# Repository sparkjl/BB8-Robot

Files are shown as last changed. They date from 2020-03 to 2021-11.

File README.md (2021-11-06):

## STAR WARS星战之旅: BB8球形机器人制作 
> 基于TI MSP-EXP430G2 LaunchPad硬件平台，软件、硬件、结构完全开源。
- 一切源于40多年的星战情怀:  
[星球大战7：原力觉醒](https://www.bilibili.com/video/av74977133?from=search&seid=1754264535096664915)
- YouTube上的BB8 Robot拆机视频:  
[今天就拆你了 Cracking Open - Sphero BB-8 Star Wars toy](https://www.bilibili.com/video/av2889876?from=search&seid=3099549580609771673)

### 1. 结构
SolidWorks渲染的结构外观:
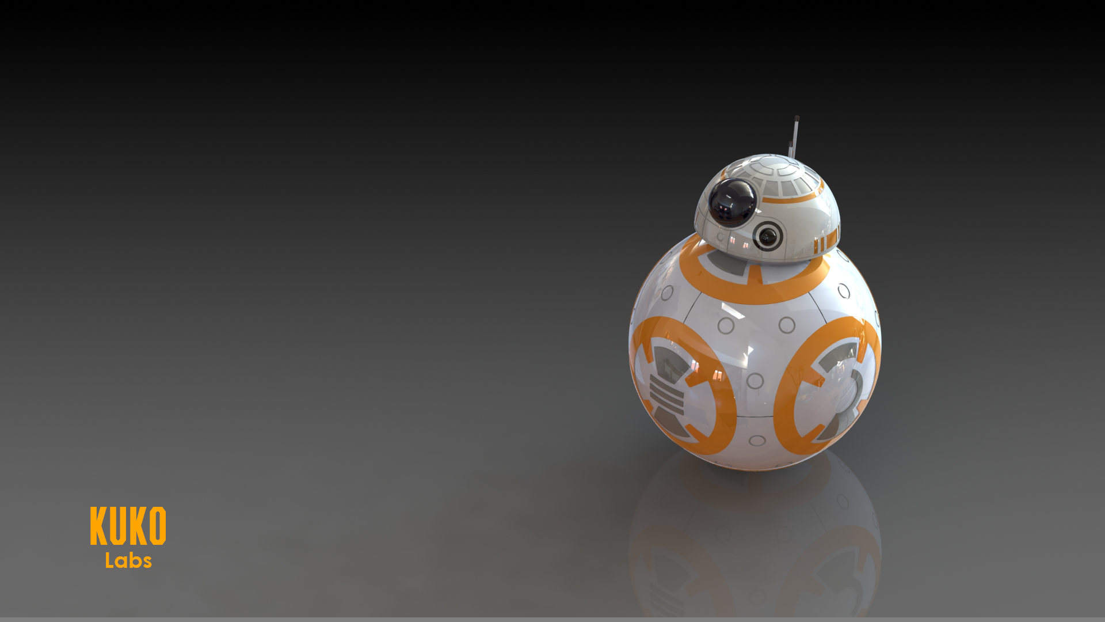
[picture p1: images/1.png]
  

### 2. 硬件
Altium Designer设计的PCB板:
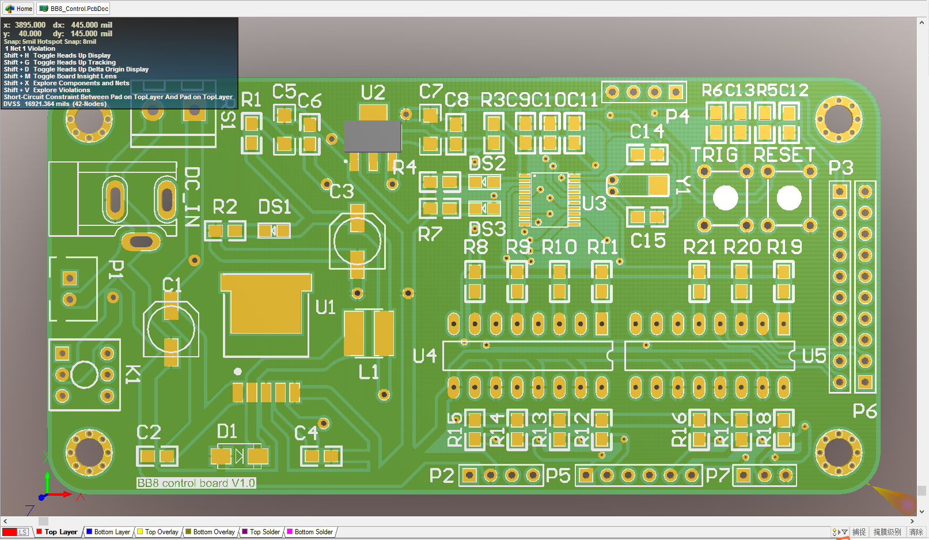
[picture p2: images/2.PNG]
  

BB8-Robot功能模块连接:
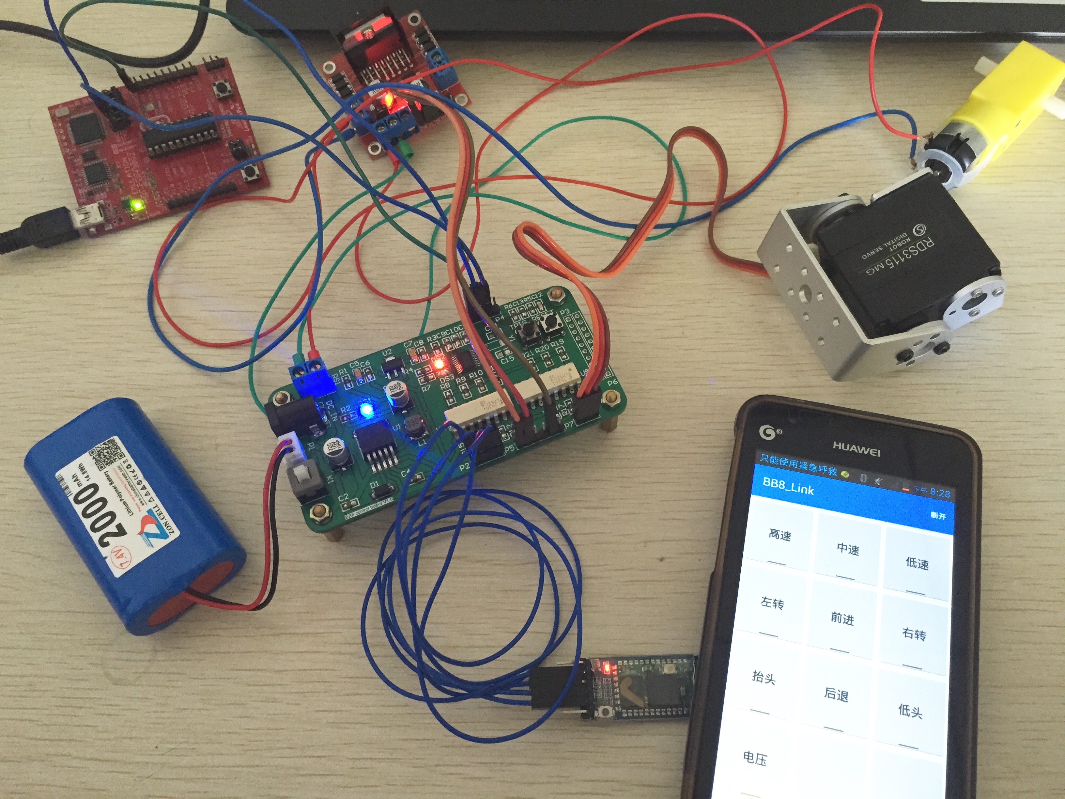
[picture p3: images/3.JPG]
  

BB8-Robot组装完毕效果:
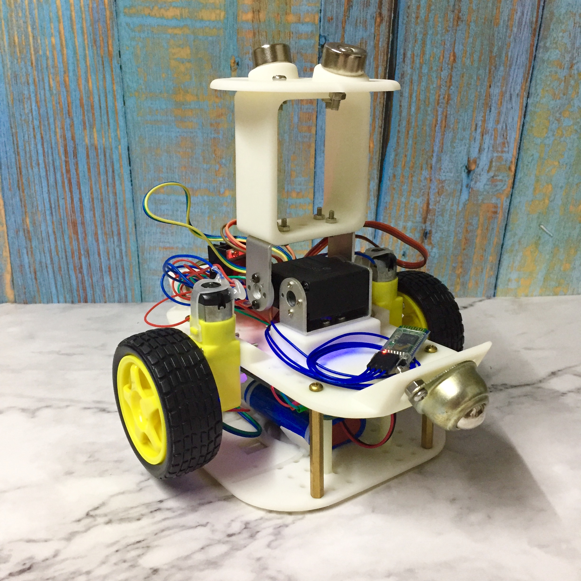
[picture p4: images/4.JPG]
  

### 3. 教程
> 关注微信公众号: **`[酷科实验室]`**, 发现更多精彩!
- [结构篇](https://mp.weixin.qq.com/s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) 
- [硬件篇](https://mp.weixin.qq.com/s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) 
- [软件篇](https://mp.weixin.qq.com/s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) 

> 联系我: spark.zheng@hotmail.com  
> @sparkjl

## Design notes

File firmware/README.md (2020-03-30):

### firmware
1. IDE: `IAR Embedded Workbench`，版本: `for MSP430 Ver5.3`及以上。
2. 硬件平台: `MSP-EXP430G2 LaunchPad`。
3. 集成接口: `mpu6050三轴加速、陀螺仪`，以供后续开发，优化运动姿态。

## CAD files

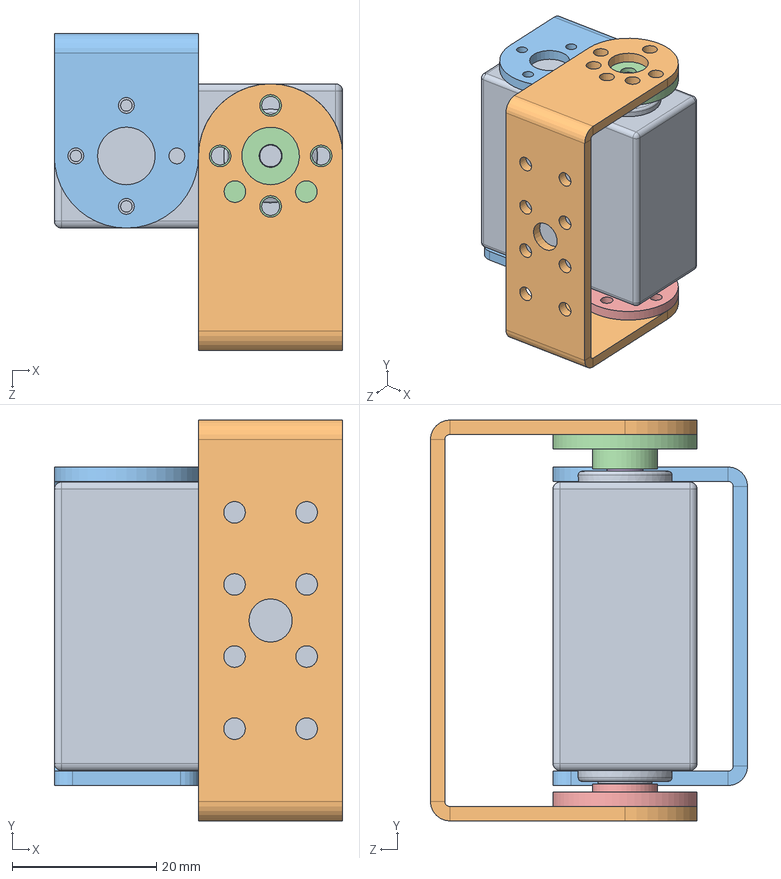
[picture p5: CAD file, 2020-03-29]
structure/舵机/舵机.SLDASM
40.0 x 55.6 x 44.0 mm
舵机体
活动臂1
活动臂2
舵盘1
舵盘2
螺栓

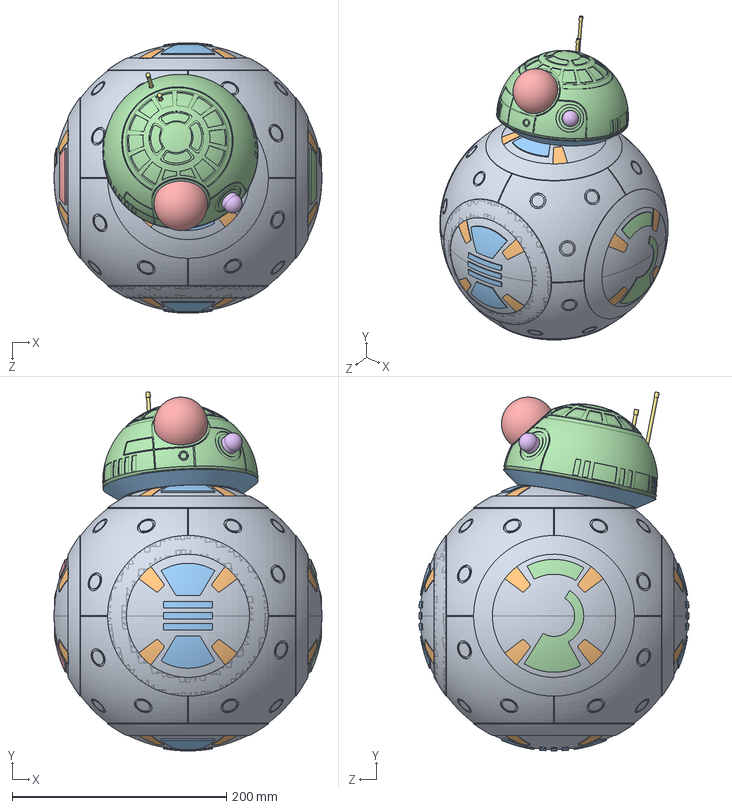
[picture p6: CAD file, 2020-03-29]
structure/BB8机器人.SLDASM
250.0 x 335.1 x 252.4 mm
外壳1 x 2
底盘1
减速电机 x 2
车轮 x 2
舵机体
活动臂1
活动臂2
舵盘1
舵盘2
螺栓
角球 x 2
脖子
底盘2
主电路板
顶盘
磁铁 x 2
电池
六角双通铜柱M4 x 8
头部转盘
头部
眼睛
探头
waike6 x 2
万向球 x 3
waike1 x 7
waike2 x 28
waike3 x 4
waike4
镜向waike4
pan head cross recess screw_iso x 55

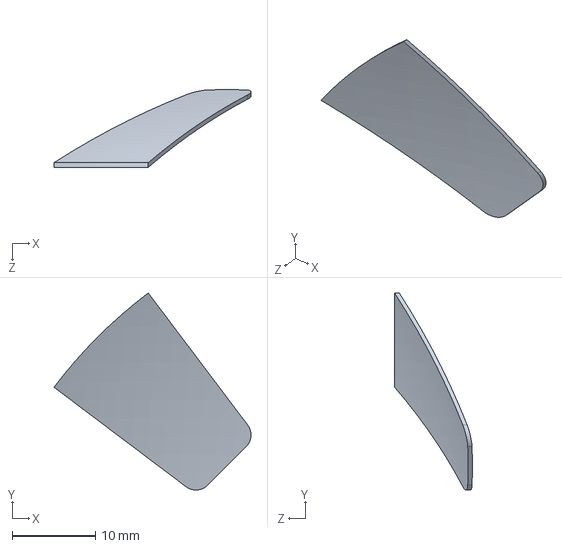
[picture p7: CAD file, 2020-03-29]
structure/外壳/waike2.sldprt
23.7 x 23.7 x 9.34 mm

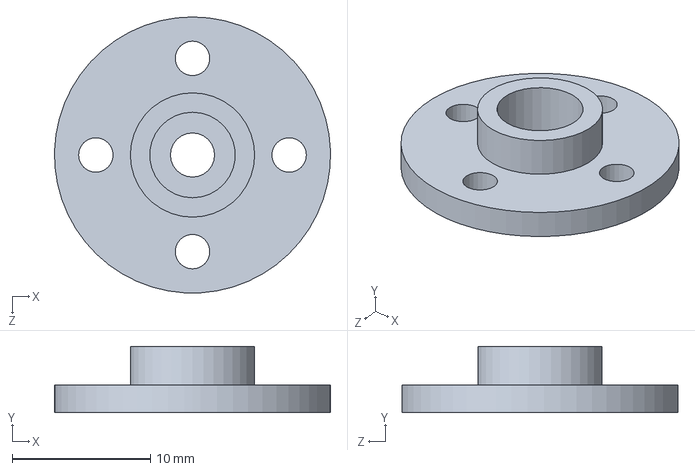
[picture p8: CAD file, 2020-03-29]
structure/舵机/舵盘1.SLDPRT
20.0 x 4.80 x 20.0 mm

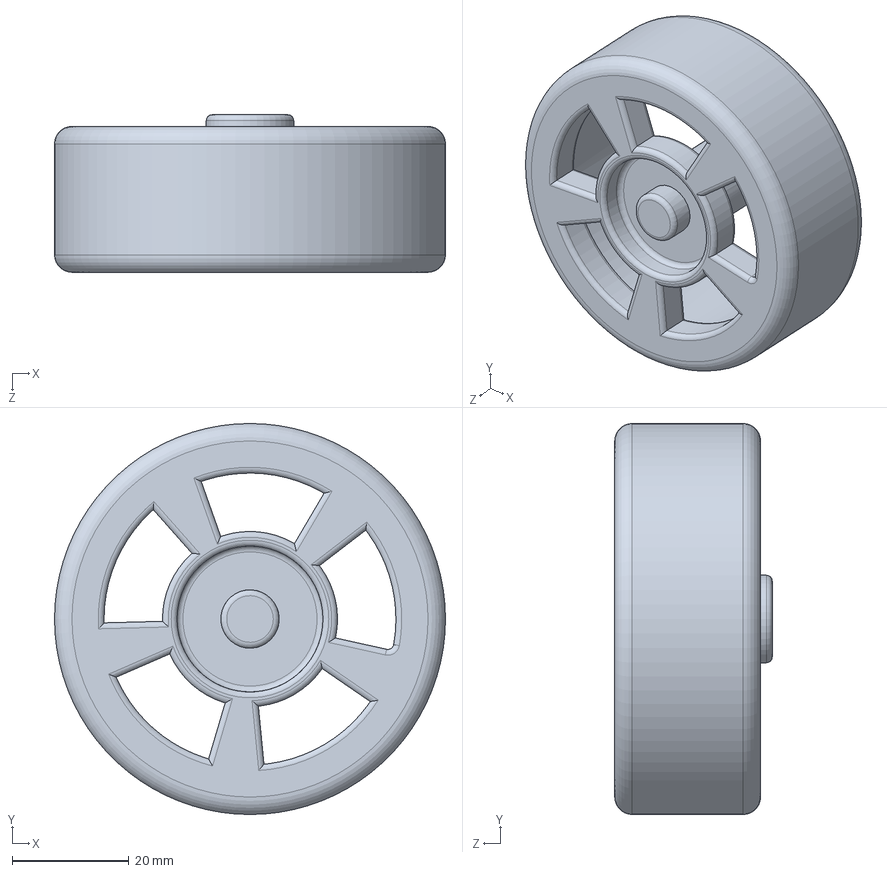
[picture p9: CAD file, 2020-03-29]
structure/车轮.SLDPRT
67.0 x 67.0 x 27.0 mm

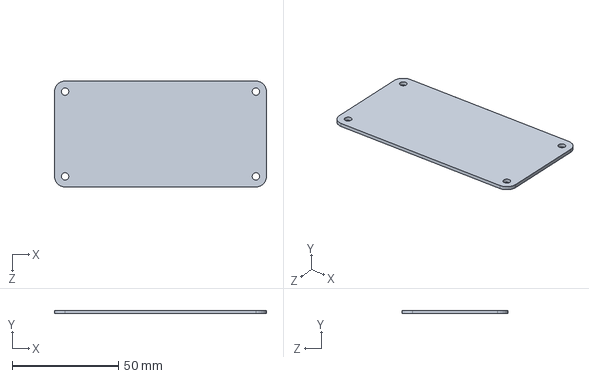
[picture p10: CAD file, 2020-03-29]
structure/主电路板.SLDPRT
100.0 x 1.60 x 50.0 mm

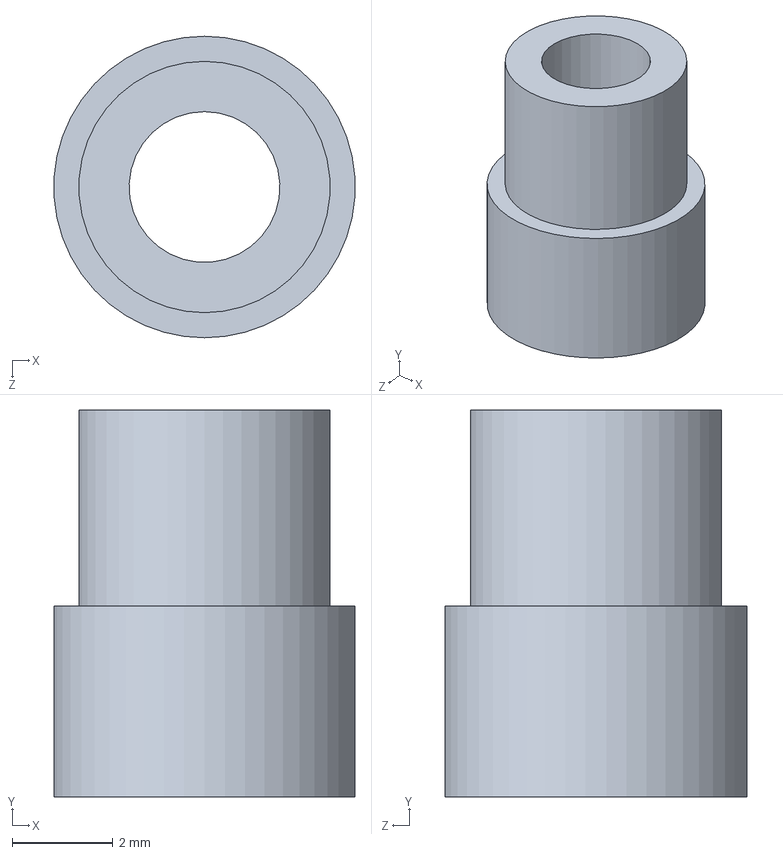
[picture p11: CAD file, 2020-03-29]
structure/舵机/螺栓.SLDPRT
5.99 x 7.70 x 6.00 mm

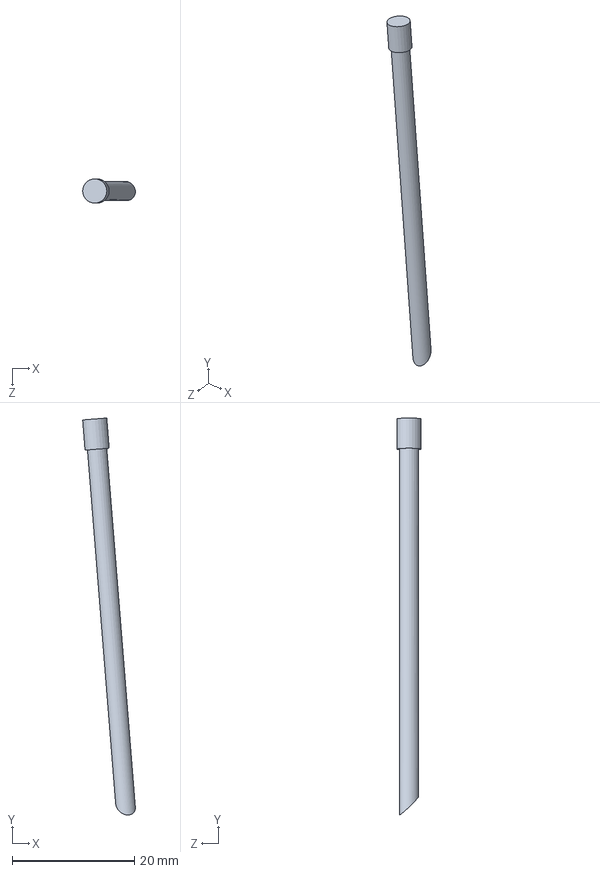
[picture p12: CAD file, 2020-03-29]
structure/外壳/waike6.sldprt
8.64 x 65.0 x 3.97 mm

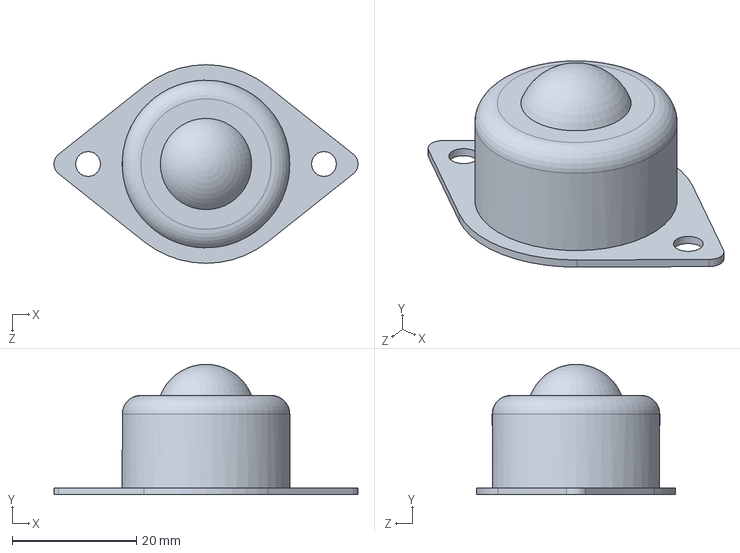
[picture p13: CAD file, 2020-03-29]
structure/角球.SLDPRT
49.0 x 21.0 x 32.0 mm

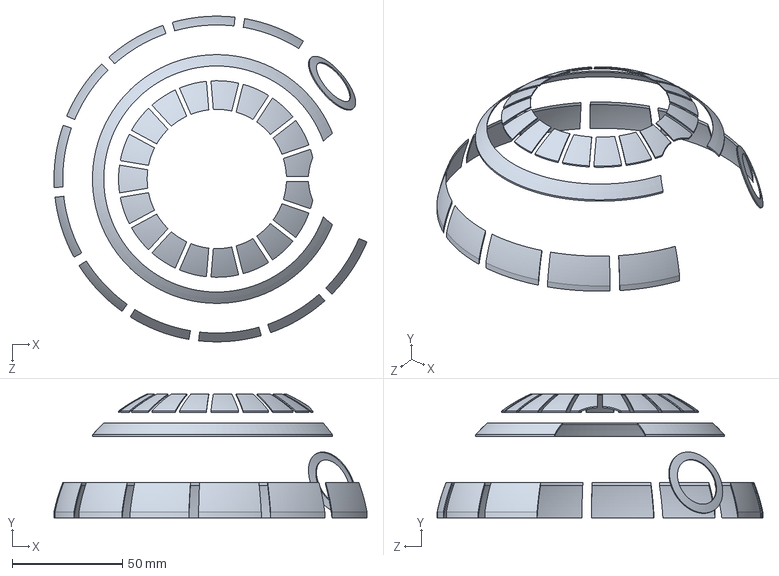
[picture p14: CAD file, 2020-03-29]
structure/外壳/waike5.sldprt
142.3 x 56.3 x 148.0 mm

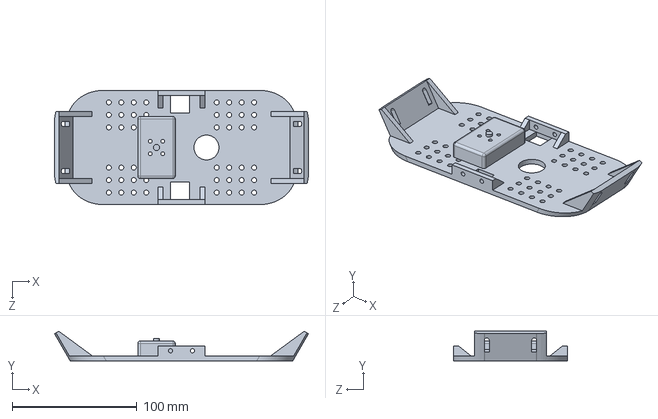
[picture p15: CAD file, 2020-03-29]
structure/底盘1.sldprt
203.5 x 23.7 x 91.5 mm

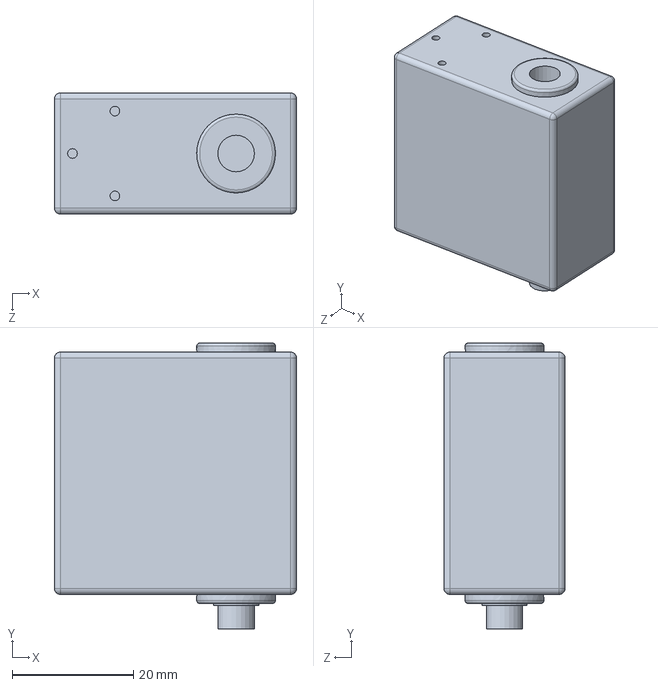
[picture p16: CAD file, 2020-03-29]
structure/舵机/舵机体.sldprt
40.0 x 47.2 x 20.0 mm

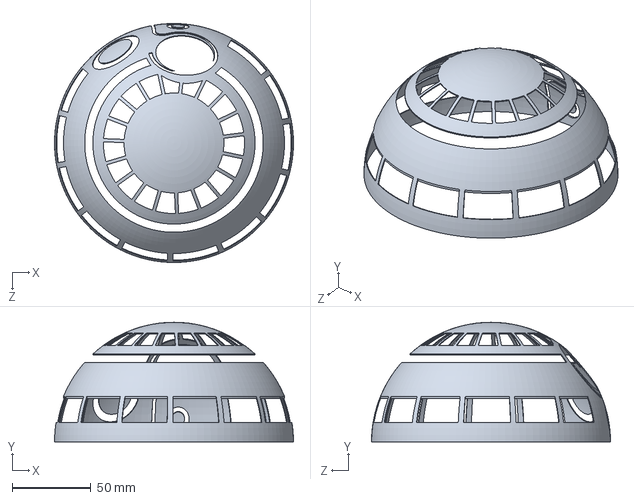
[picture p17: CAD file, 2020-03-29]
structure/外壳/waike7.sldprt
151.4 x 75.7 x 151.4 mm

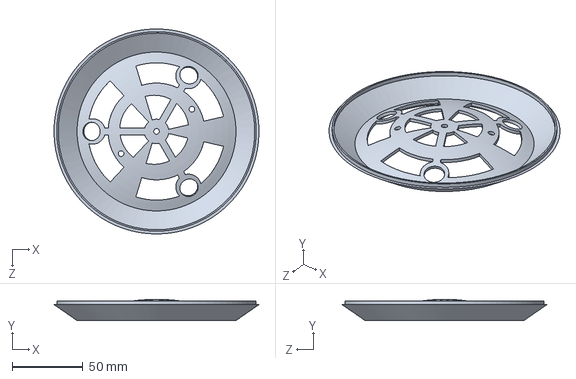
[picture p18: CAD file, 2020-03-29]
structure/头部转盘.sldprt
145.0 x 15.1 x 144.9 mm

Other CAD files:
structure/外壳/镜向waike4.sldprt
structure/舵机/活动臂1.SLDPRT
structure/万向球.SLDPRT
structure/外壳/waike3.sldprt
structure/六角双通铜柱M4.sldprt
structure/减速电机.SLDPRT
structure/外壳/waike1.sldprt
structure/外壳/waike4.sldprt
structure/外壳1.sldprt
structure/头部.SLDPRT
structure/底盘2.sldprt
structure/探头.SLDPRT
structure/电池.SLDPRT
structure/眼睛.SLDPRT
structure/磁铁.SLDPRT
structure/脖子.sldprt
structure/舵机/活动臂2.SLDPRT
structure/舵机/舵盘2.SLDPRT
structure/顶盘.sldprt

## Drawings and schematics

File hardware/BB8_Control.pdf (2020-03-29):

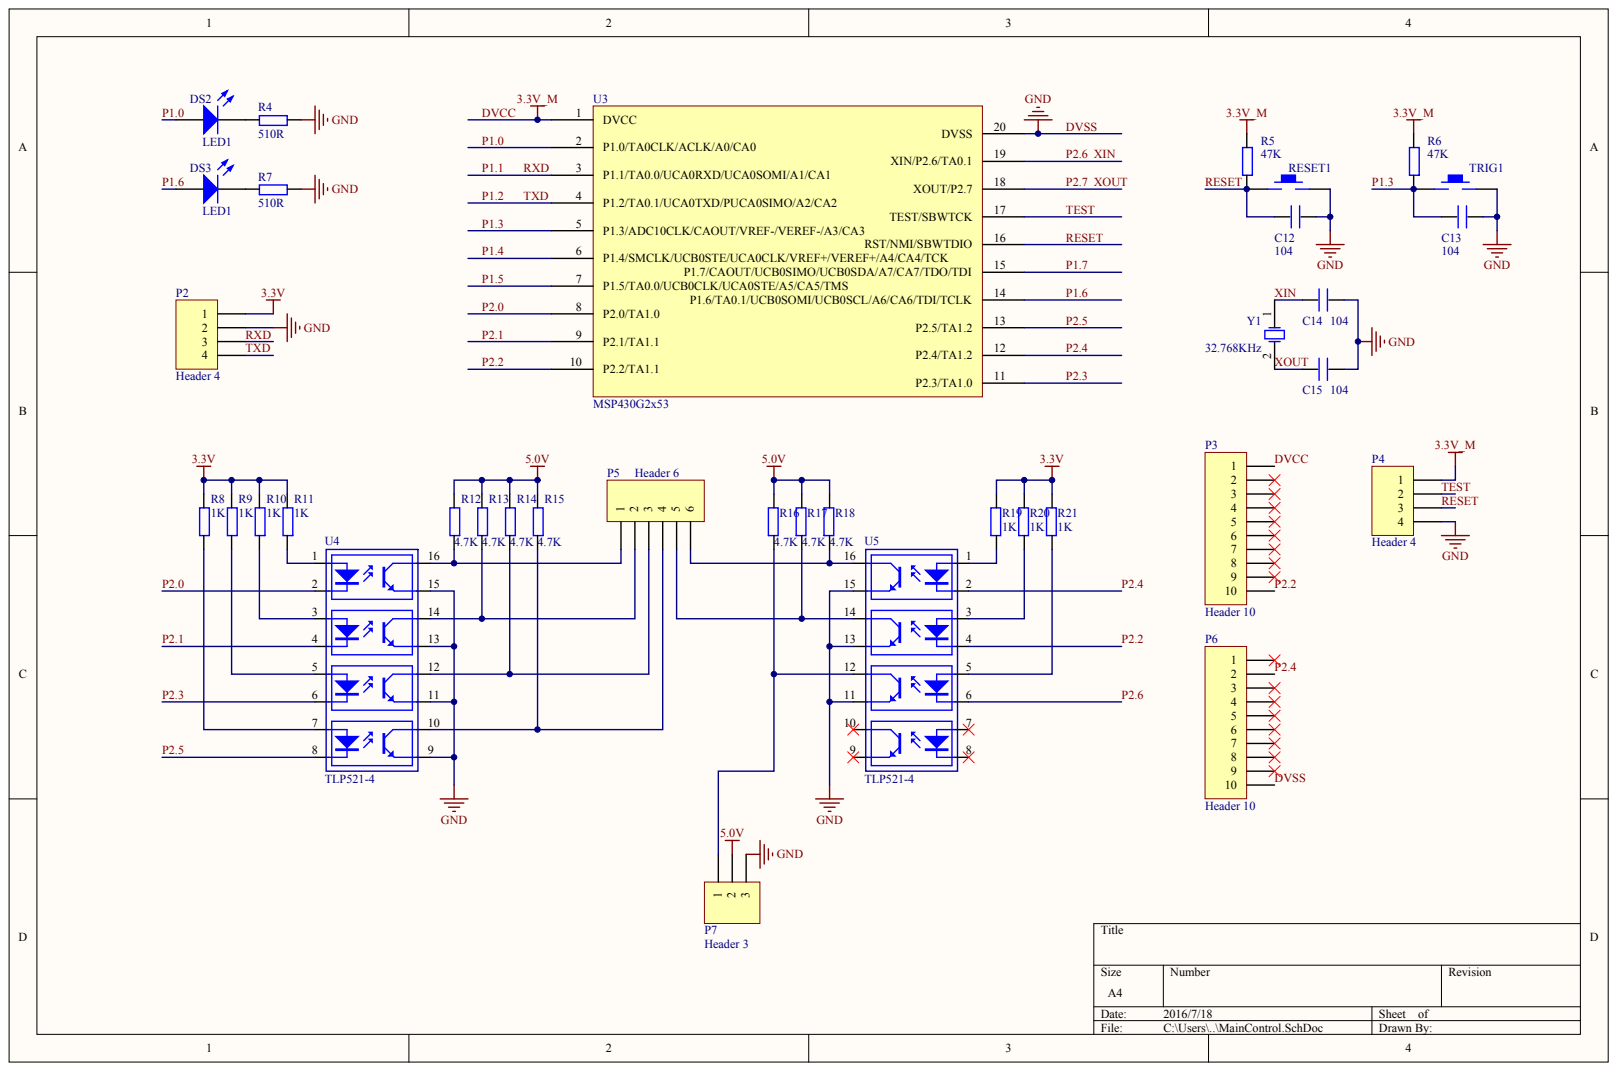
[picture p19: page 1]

P1.4/SMCLK/UCB0STE/UCA0CLK/VREF+/VEREF+/A4/CA4/TCK 6

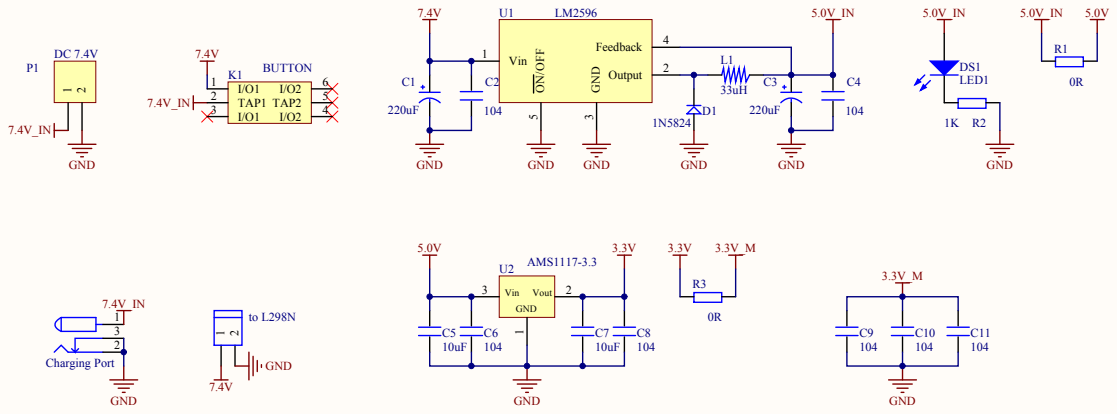
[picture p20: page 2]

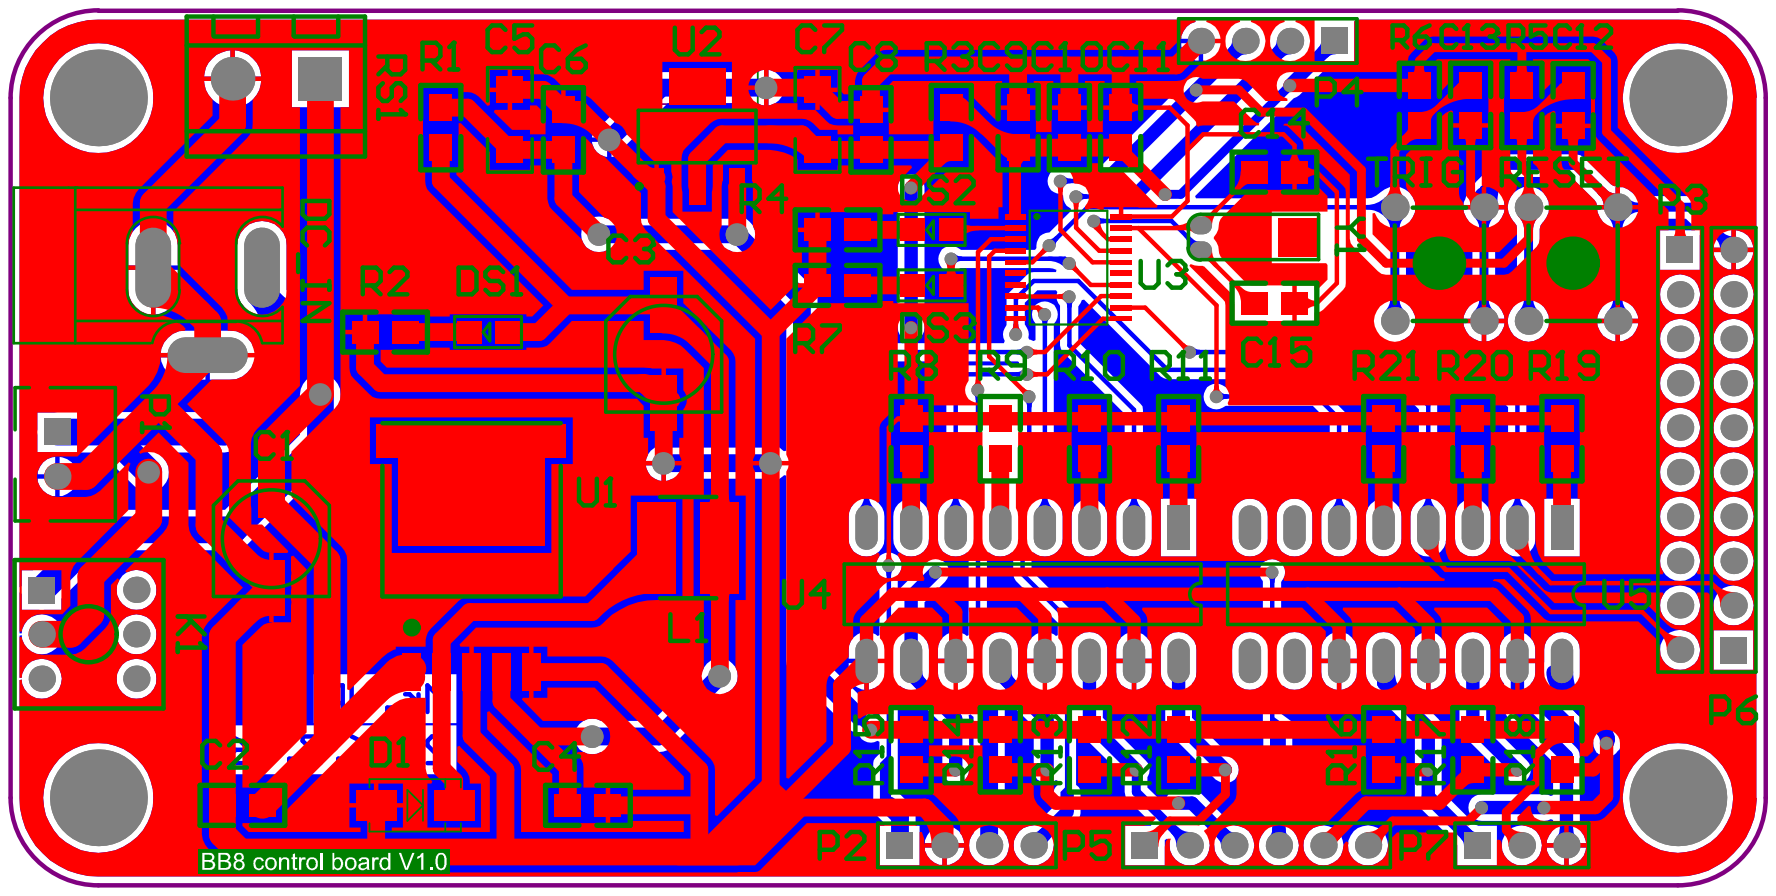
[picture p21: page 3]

Bill of Materials | <Parameter Title not found>
Source Data From: | BB8_Control.PrjPCB
Project: | | BB8_Control.PrjPCB
Variant: | | None
Creation Date: 2016/7/18 | 15:20:54
Print Date: | 42569 | 42569.63968
Footprint | Comment | LibRef | Designator | Description | Quantity
CC6.56.5 | 220uF | CAP | C1, C3 | | 2
0603P | 104 | C | C2, C4, C6, C8, C9, C10, C11, C12, C13,
| | | C14, C15 | | 11
0603P | 10uF | C | C5, C7 | | 2
DIODE_SOP | 1N5824 | D | D1 | | 1
DC10B | Charging Port | POW | DC_IN1 | | 1
SMDLED | LED1 | LE, LED2 | DS1, DS2, DS3 | Typical RED, GREEN, YELLOW, AMBER
| | | | GaAs LED | 3
BTN8.5*8.5 | BUTTON | BUTTON | K1 | | 1
CD54 | 33uH | L | L1 | | 1
XH2.54-2P | DC 7.4V | Header-2 | P1 | Header, 2-Pin | 1
HDR1X4 | Header 4 | Header 4 | P2, P4 | Header, 4-Pin | 2
HDR1X10 | Header 10 | Header 10 | P3, P6 | Header, 10-Pin | 2
HDR1X6 | Header 6 | Header 6 | P5 | Header, 6-Pin | 1
HDR1X3 | Header 3 | Header 3 | P7 | Header, 3-Pin | 1
0603P | 0R | R | R1, R3 | | 2
0603P | 1K | R | R2, R8, R9, R10, R11, R19, R20, R21 | | 8
0603P | 510R | R | R4, R7 | | 2
0603P | 47K | R | R5, R6 | | 2
0603P | 4.7K | R | R12, R13, R14, R15, R16, R17, R18 | | 7
KEY_M | KEY_M | K | RESET1, TRIG1 | | 2
HEAD2L-0.8 | to L298N | H | RS1 | | 1
TO-263-5 | LM2596 | LM2596 | U1 | LM2596 - 5.0 | 1
SOT223-4L | AMS1117-3.3 | AMS1117 | U2 | AMS1117-3.3 | 1

## MSP430G2x

53 | MSP430G2x53 | MSP430G2x53 | U3 | MSP430G2x53 microcontrollers | 1
DIP16 | TLP521-4 | TLP521-4 | U4, U5 | 4 x 4-Pin Phototransistor Optocoupler | 2
XTAL32 | 32.768KHz | XT | Y1 | Crystal Oscillator | 1
| | | | | 59
Approved | | Notes

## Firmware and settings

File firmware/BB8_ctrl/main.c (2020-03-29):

#include "io430.h"
#include "config.h"
#include "USCI.h"
#include "Timer_A.h"
//#include "IIC.h"
//#include "mpu6050.h"
//#include "inv_mpu.h"
//#include "inv_mpu_dmp_motion_driver.h"
//#include "ANO_Tech.h"

int main(void)
{ 
//  float temp = 0.0;
  char str[80];
//  short gx, gy, gz;
//  short ax, ay, az;
  USCIA0_Get_Flag = 0;
  USCIA0_Get_Data = 0;
  
  unsigned char CMD = 0;  //从蓝牙接收的控制指令
  unsigned char Speed_init = 0;  //初始速度
  unsigned char Speed_control = 150;  //控制速度
  unsigned char Angle_control = 90;  //控制角度
  
  WDT_init();  
  CLK_config();
  Port_init();
  UART_init();
  PWM_config();
//  IIC_init();
//  mpu6050_init();
  
  Servo_Angle_Control(Angle_control, Angle_control);
  while(1)
  {
//    LED1_ON;
//    LED2_OFF;
//    delay_ms(20);
//    LED1_OFF;
//    LED2_ON;
//    delay_ms(20);
//    UART_SendString("BB8 is working...\r\n");
    //while(mpu_dmp_init())
//    while(mpu6050_init())
//    {
//      UART_SendString("MPU6050 error !!!\r\n");  
//    }
//    UART_SendString("MPU6050 is working...\r\n");
    
//    temp = mpu6050_Get_Temperature();
//    mpu6050_Get_Gyroscope(&gx, &gy, &gz);
//    mpu6050_Get_Accelerometer(&ax, &ay, &az);
    
//    sprintf(str, "温度: %f\r\n", temp);
//    UART_SendString((unsigned char *)str);
//    sprintf(str, "gx: %d;gy: %d;gz: %d\r\n", gx, gy, gz);
//    UART_SendString((unsigned char *)str);
//    sprintf(str, "ax: %d;ay: %d;az: %d\r\n", ax, ay, az);
//    UART_SendString((unsigned char *)str);
    if(USCIA0_Get_Flag)  //收到蓝牙发送的数据
    {
//      sprintf(str, "CMD: %d;Speed_init: %d;Speed_control: %d;Angle_control: %d\r\n", CMD, Speed_init, Speed_control, Angle_control);
//      UART_SendString((unsigned char *)str);      
      CMD = USCIA0_Get_Data;  //更新控制指令
      USCIA0_Get_Flag = 0;
    }
    else if(CMD == 'v')  //检测电压
    {
      /***/
      CMD = 't';
    }
    else if(CMD == 'h')  //高速模式
    {
      Speed_control = 240;
      CMD = 't';
    }
    else if(CMD == 'm')  //中速模式
    {
      Speed_control = 160;
      CMD = 't';
    }
    else if(CMD == 'l')  //低速模式
    {
      Speed_control = 100;
      CMD = 't';
    }    
    else if(CMD == '1')  //前进
    {
      Servo_Angle_Control(110, Angle_control);
      Angle_control = 110;
      
      Speed_init = 80;
      while(CMD == '1')
      {
        if(USCIA0_Get_Flag)
        {
          CMD = USCIA0_Get_Data;
          USCIA0_Get_Flag = 0;
        }
        else if(Speed_init < Speed_control)  //匀加速
        {
          Speed_init++;
          Motor_Speed_Control(Speed_init, Speed_init);
          delay_ms(10);
        }
        else
        {
          Motor_Speed_Control(Speed_control, Speed_control);
          delay_ms(10);
        }
      }
      while(Speed_init > 80)  //匀减速
      {
        Speed_init--;
        Motor_Speed_Control(Speed_init, Speed_init);
        delay_ms(10);
      }
      Servo_Angle_Control(90, Angle_control);
      Angle_control = 90;      
    }
    else if(CMD == '2')  //右转
    {
      Motor_Speed_Control(-Speed_control, Speed_control);
      delay_ms(10);
    }
    else if(CMD == '3')  //左转
    {
      Motor_Speed_Control(Speed_control, -Speed_control);
      delay_ms(10);
    }
    else if(CMD == '4')  //后退
    {
      Servo_Angle_Control(70, Angle_control);
      Angle_control = 70;
      
      Speed_init = 80;
      while(CMD == '4')
      {
        if(USCIA0_Get_Flag)
        {
          CMD = USCIA0_Get_Data;
          USCIA0_Get_Flag = 0;
        }
        else if(Speed_init < Speed_control)  //匀加速
        {
          Speed_init++;
          Motor_Speed_Control(-Speed_init, -Speed_init);
          delay_ms(10);
        }
        else
        {
          Motor_Speed_Control(-Speed_control, -Speed_control);
          delay_ms(10);          
        }
      }
      while(Speed_init > 80)  //匀减速
      {
        Speed_init--;
        Motor_Speed_Control(-Speed_init, -Speed_init);
        delay_ms(10);
      }
      Servo_Angle_Control(90, Angle_control);
      Angle_control = 90;      
    }
    else if(CMD == '5' && Angle_control < 140)  //抬头
    {
      Servo_Angle_Control(140, Angle_control);
      Angle_control = 140;      
    }
    else if(CMD == '6' && Angle_control > 50)  //低头
    {
      Servo_Angle_Control(50, Angle_control);
      Angle_control = 50;       
    }
    else if(CMD == '7')
    {
      Servo_Angle_Control(90, Angle_control);
      Angle_control = 90;      
    }
    else if(CMD == '8')
    {
      /***/
    }
    else if(CMD == '9')
    {
      /***/
    }
    else
    {
      Motor_Speed_Control(0, 0);
      delay_ms(10);
    }
 
  }  
}

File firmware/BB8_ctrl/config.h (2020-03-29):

#ifndef __CONFIG_H
#define __CONFIG_H
#include "io430.h"
#include "stdio.h"

#define uchar unsigned char
#define uint  unsigned int
#define ulong unsigned long

#define CPU_F  ((double)12000000)
#define delay_us(x)  __delay_cycles((long)(CPU_F * (double)x / 1000000.0))
#define delay_ms(x)  __delay_cycles((long)(CPU_F * (double)x / 1000.0))

#define LED1_ON   P1OUT |= BIT0
#define LED1_OFF  P1OUT &= ~BIT0
#define LED2_ON   P1OUT |= BIT6
#define LED2_OFF  P1OUT &= ~BIT6

void CLK_config(void);
void WDT_init(void);
void Port_init(void);
void Delay_nms(unsigned int n);

#endif

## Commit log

2020-03-29 add 3d models
    [BB8机器人.SLDASM, waike1.sldprt, waike2.sldprt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]
2020-03-29 add pcb doc
    [BB8_Control.PcbDoc, BB8_Control.PrjPCB, MainControl.SchDoc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]
